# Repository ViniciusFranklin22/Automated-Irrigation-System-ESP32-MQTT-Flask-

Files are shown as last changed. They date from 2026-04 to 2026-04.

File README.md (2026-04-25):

# 🌿 Smart Irrigation System with ESP32 and IoT

This project was developed for real-time plant monitoring and automatic irrigation using ESP32, MQTT, and a web-based interface.

## 🚀 Features

- 📡 Real-time monitoring:
  - Soil moisture
  - Temperature
  - Air humidity
  - Light intensity

- 💧 Irrigation:
  - Manual (via web button)
  - Automatic (based on soil moisture threshold)

- ⚙️ Remote configuration:
  - Minimum soil moisture threshold
  - Minimum interval between irrigations
  - Pump activation time
  - Enable/disable automatic mode
  - Configuration is stored in ESP32 non-volatile memory, ensuring persistence after reboot

- 💡 System status indicators:
  - LED indicator for Wi-Fi connection status  
  - LED indicator for MQTT connection status  
  - Provides quick visual feedback for system debugging and reliability

- 📊 Web dashboard:
  - Historical graphs (24h, 48h, 1 week)
  - Device online/offline status
  - Last irrigation timestamp
  - Real data collected over several days
  - Clear visualization of sensor behavior, including soil moisture variation after irrigation events

## 🧠 Architecture

ESP32 → MQTT → Backend (Flask) → Web Dashboard  
ESP32 ← MQTT ← Backend (Flask) ← Web Dashboard  

- ESP32 publishes sensor data via MQTT  
- Backend stores data in CSV files using Pandas  
- Web interface consumes data through a Flask API  
- Commands are sent to the ESP32 via MQTT  

## 🛠️ Technologies Used

- Python (Flask, Pandas)  
- MQTT (paho-mqtt)  
- ESP32 (Arduino framework)  
- HTML + Bootstrap + Chart.js  
- KiCad  

## 🔌 Hardware Implementation

- Prototype built using a breadboard for data acquisition and testing  
- Sensors and ESP32 connected for real-world measurements  
- System validated with real environmental data over multiple days  

<p align="center">
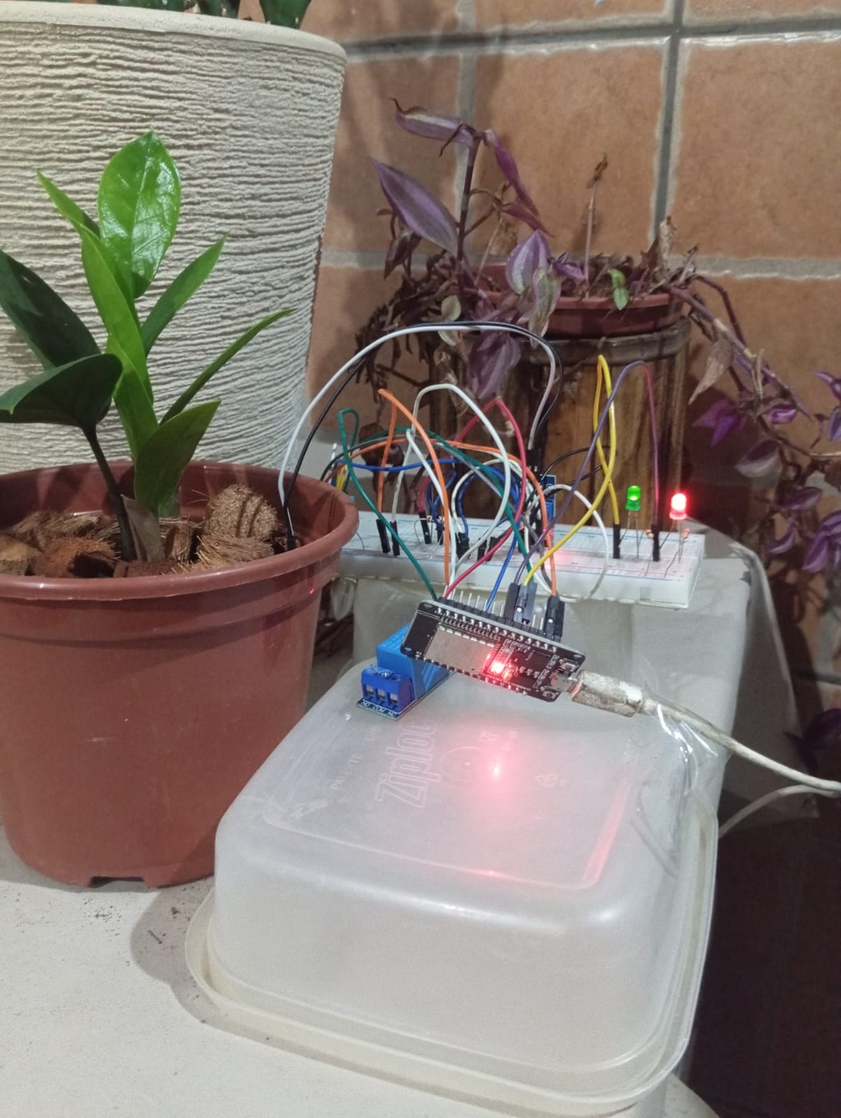
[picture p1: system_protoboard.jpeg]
  
</p>

## 🧩 PCB Design

- Custom PCB designed using KiCad  
- Developed aiming toward a future product-ready solution  

## 📷 Interface

<p align="center">
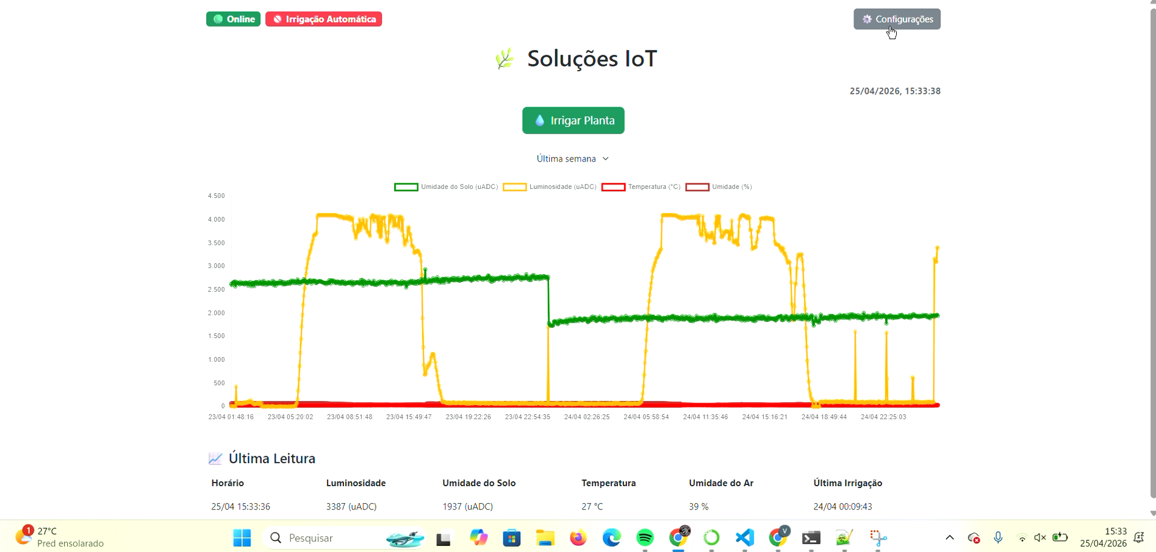
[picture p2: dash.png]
  
</p>

## ▶️ How to Run

1. Configure your MQTT broker  
2. Adjust file paths in the code  
3. Run the data collection scripts:
   - `server_get_msg.py`
   - `server_get_msg_irrig.py`
4. Start the Flask application:
   ```bash
   python main_flask.py

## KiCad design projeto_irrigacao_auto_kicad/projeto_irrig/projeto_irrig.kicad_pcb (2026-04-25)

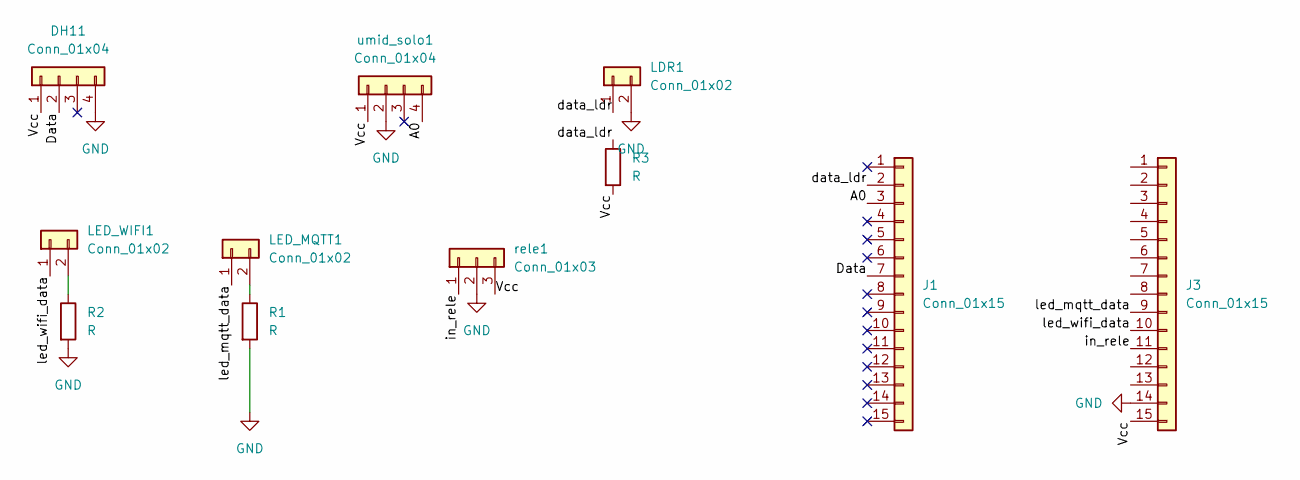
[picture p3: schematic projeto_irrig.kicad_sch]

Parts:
DH11: Conn_01x04; PinHeader_1x04_P2.54mm_Vertical
J1, J3: Conn_01x15; PinHeader_1x15_P2.54mm_Vertical
LDR1: Conn_01x02; PinHeader_1x02_P2.54mm_Vertical
LED_MQTT1: Conn_01x02; PinHeader_1x02_P2.54mm_Vertical
LED_WIFI1: Conn_01x02; PinHeader_1x02_P2.54mm_Vertical
R1, R2, R3: R; R_Axial_DIN0207_L6.3mm_D2.5mm_P7.62mm_Horizontal
rele1: Conn_01x03; PinHeader_1x03_P2.54mm_Vertical
umid_solo1: Conn_01x04; PinHeader_1x04_P2.54mm_Vertical

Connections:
/A0: J1.3, umid_solo1.4
/Data: DH11.2, J1.7
/Vcc: DH11.1, J3.15, R3.2, rele1.3, umid_solo1.1
/data_ldr: J1.2, LDR1.1, R3.1
/in_rele: J3.11, rele1.1
/led_mqtt_data: J3.9, LED_MQTT1.1
/led_wifi_data: J3.10, LED_WIFI1.1
GND: DH11.4, J3.14, LDR1.2, R1.2, R2.2, rele1.2, umid_solo1.2
unnamed: LED_MQTT1.2, R1.1
unnamed: LED_WIFI1.2, R2.1

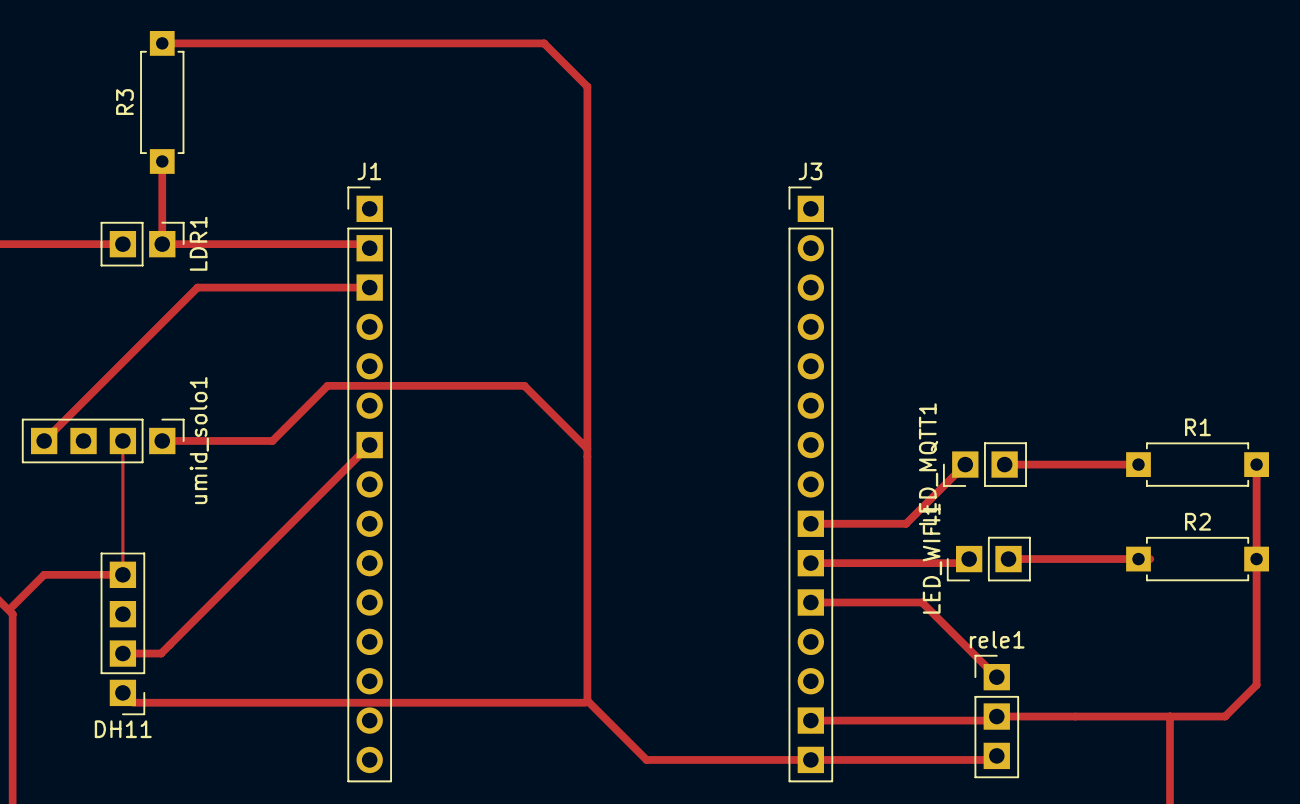
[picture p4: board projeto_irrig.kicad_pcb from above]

Board: 2 copper layers, 11 parts (0 on the bottom side), 10 nets.

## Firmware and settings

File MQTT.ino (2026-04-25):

/*
 * This ESP32 code is created by esp32io.com
 *
 * This ESP32 code is released in the public domain
 *
 * For more detail (instruction and wiring diagram), visit https://esp32io.com/tutorials/esp32-mqtt
 */


/*
Smart Plant Monitoring System
ESP32 + MQTT + Sensors

Features:
- Soil humidity monitoring
- Automatic irrigation
- Remote irrigation via MQTT
- Configurable thresholds
- Real time telemetry
- NTP timestamp
- WiFi + MQTT auto reconnection
*/

#include <WiFi.h>
#include <MQTTClient.h>
#include <ArduinoJson.h>
#include <time.h>
//#include <bits/stdc++.h>
#include <DHT11.h>
#include <Preferences.h>
Preferences prefs;


struct DHTData {
  int temperatura;
  int umidade;
};

// ===== PROTOTIPOS DAS FUNCOES =====

void connectToMQTT();
float get_ldr_value();
DHTData get_dht11_values();
float get_soil_humidity();
void regar_vaso_auto();
void check_threshold();
void sendToMQTT();
void messageHandler(String &topic, String &payload);
String get_real_time();
void regar_vaso_manual();
void reconnectToWiFi();
void ligar_bomba();
void create_var_flash();
void setUIntFromPayload(const char* key, String payload, uint &targetVar);

#define CLIENT_ID "ESP32-001"  // CHANGE IT AS YOU DESIRE

#define D_TEMP_PIN 33
#define DHT_READ_TIME 100000


DHT11 dht11(D_TEMP_PIN);
const char WIFI_SSID[] = "";              // CHANGE TO YOUR WIFI SSID
const char WIFI_PASSWORD[] = "";           // CHANGE TO YOUR WIFI PASSWORD
const char MQTT_BROKER_ADRRESS[] = "";  // CHANGE TO MQTT BROKER'S IP ADDRESS
const int MQTT_PORT = 1883;
const char MQTT_USERNAME[] = "";  // CHANGE IT IF REQUIRED
const char MQTT_PASSWORD[] = "";  // CHANGE IT IF REQUIRED
volatile bool flag = false;
String hora_ultima_irrigacao="0";
DHTData dht_cache;
unsigned long lastDHTRead = 0;
long timezone = -3;
byte daysavetime = 0;

// The MQTT topics that this device should publish/subscribe
unsigned long lastAutoCheck = 0;
int AUTO_CHECK_INTERVAL = 10000; // 10 segundos
bool irrigacao_em_curso = 0;

//#define LM75_ADDRESS 0x48  // Endereço padrão do LM75
//#define TEMP_REGISTER 0x00 // Registro de leitura de temperatura
#define PUBLISH_TOPIC "esp32-001/send"
#define INICIO_IRRIGACAO_PUBLISH_TOPIC "esp32-001/inicio_irrigacao"
#define SUBSCRIBE_TOPIC "esp32-001/receive"
#define TOPIC_CONFIG_THSHOLD "esp32-001/thshold"
#define TOPIC_CONFIG_MIN_ENTRE_IRRIGACAO "esp32-001/min_entre_irrigacao"
#define TOPIC_CONFIG_TEMPO_IRRIGACAO "esp32-001/tempo_irrigacao"
#define TOPIC_BOOL_IRRIGACAO_AUTO "esp32-001/auto_mode"
#define PINO_LED_WIFI 16 
#define PINO_LED_MQTT 17 
#define RW_MODE false
#define RO_MODE true
#define A0_LDR_PIN 36  
#define A1_HUM_PIN 39
//#define I2C_SDA 21  // SDA padrão no ESP32 DevKit v1
//#define I2C_SCL 22  // SCL padrão no ESP32 DevKit v1
#define PUBLISH_INTERVAL 1000  // 1 seconds
//#define TEMPO_RELE_ATIVO 5000 // tempo para irrigacao, era bom setar via MQTT, da liberdade ao user
#define RelePin  4 // pino ao qual o Módulo Relé está conectado
//#define tempo_min_entre_irrigacoes 1000 * 60 * 60 * 4 // era bom setar via MQTT, da liberdade ao user

WiFiClient network;
MQTTClient mqtt = MQTTClient(256);

// serao setadas a partir da memoria flash
bool irrig_auto; 
uint threshold_humidity; // so para testes como nao ta conectado a nada, era bom setar via MQTT, da liberdade ao user
uint TEMPO_RELE_ATIVO ;
uint tempo_min_entre_irrigacoes;

void create_var_flash(){


  prefs.begin("config", RO_MODE);           // Open our namespace (or create it if it doesn't exist) in RO mode.

  bool tpInit = prefs.isKey("nvsInit");       // Test for the existence of the "already initialized" key.
                                                
  if (tpInit == false) {
    
    prefs.end();
    prefs.begin("config", RW_MODE);
    // salvar valores de fabrica

    prefs.putBool("irrig_auto",0);
    prefs.putUInt("threshold_humidity",4000);
    prefs.putUInt("TEMPO_RELE_ATIVO",5000);
    prefs.putUInt("tempo_min_entre_irrigacoes",14400000); // 1000 * 60 * 60 * 4
    prefs.putBool("nvsInit", true); 
    prefs.end();
    prefs.begin("config", RO_MODE); 

  }

  irrig_auto = prefs.getBool("irrig_auto"); // flash
  threshold_humidity = prefs.getUInt("threshold_humidity"); // so para testes como nao ta conectado a nada, era bom setar via MQTT, da liberdade ao user
  TEMPO_RELE_ATIVO = prefs.getUInt("TEMPO_RELE_ATIVO");
  tempo_min_entre_irrigacoes = prefs.getUInt("tempo_min_entre_irrigacoes");
  // All done. Last run state (or the factory default) is now restored.
  prefs.end();

}

unsigned long ultima_irrigacao = 0;
unsigned long lastPublishTime = 0;

//float threshold_humidity = 2500;  // valor ADC para iniciar irrigação
int soil_cache;

void setup() {
  Serial.begin(115200);

  create_var_flash();

  //Wire.begin(I2C_SDA, I2C_SCL);  //  , SCL = GPIO 22 padrão no ESP32
  pinMode(RelePin, OUTPUT); // seta o pino como saída
  digitalWrite(RelePin, LOW); // seta o pino com nivel logico baixo

  pinMode(PINO_LED_WIFI,OUTPUT);
  pinMode(PINO_LED_MQTT,OUTPUT);
  digitalWrite(PINO_LED_WIFI,LOW);
  digitalWrite(PINO_LED_MQTT,LOW);

  // set the ADC attenuation to 11 dB (up to ~3.3V input)
  analogSetAttenuation(ADC_11db);
  WiFi.mode(WIFI_STA);
  WiFi.begin(WIFI_SSID, WIFI_PASSWORD);


  Serial.println("ESP32 - Connecting to Wi-Fi");

  while (WiFi.status() != WL_CONNECTED) {
    
    Serial.print(".A");
    digitalWrite(PINO_LED_WIFI,LOW);
    delay(500);
  }
  Serial.print("ESP32 IP Address: ");
  Serial.println(WiFi.localIP());
  digitalWrite(PINO_LED_WIFI,HIGH);
  //Serial.print("Ping broker: ");
  //Serial.println(WiFi.ping("192.168.0.174"));


  Serial.println();

  mqtt.begin(MQTT_BROKER_ADRRESS, MQTT_PORT, network);
  // Create a handler for incoming messages
  mqtt.onMessage(messageHandler);

  connectToMQTT();

  Serial.println("Contacting Time Server");
  configTime(3600 * timezone, daysavetime * 3600, "time.nist.gov", "0.pool.ntp.org", "1.pool.ntp.org");

}



void reconnectToWiFi() {

  if (WiFi.status() == WL_CONNECTED){
    digitalWrite(PINO_LED_WIFI,HIGH);
    return;
    }

  Serial.println("Reconectando ao WiFi...");

  WiFi.begin(WIFI_SSID, WIFI_PASSWORD);

  while (WiFi.status() != WL_CONNECTED) {
    Serial.print(".W");
    digitalWrite(PINO_LED_WIFI,LOW);
    delay(500);
  }
  digitalWrite(PINO_LED_WIFI,HIGH);
  Serial.println("\nWiFi reconectado!");
}

void connectToMQTT() {
  // Connect to the MQTT broker
  if (mqtt.connected()) {
    digitalWrite(PINO_LED_MQTT,HIGH);
    return;
    }
  

  Serial.print("ESP32 - Connecting to MQTT broker");

  while (!mqtt.connect(CLIENT_ID, MQTT_USERNAME, MQTT_PASSWORD) && WiFi.status() == WL_CONNECTED) {
    Serial.print(".B");
    digitalWrite(PINO_LED_MQTT,LOW);
    delay(100);
    }

  Serial.println();

  if (!mqtt.connected()) {
    Serial.println("ESP32 - MQTT broker Timeout!");
    return;
  }

  // Subscribe to a topic, the incoming messages are processed by messageHandler() function
  if (mqtt.subscribe(SUBSCRIBE_TOPIC)) {
      Serial.print("ESP32 - Subscribed to the topic: ");
      Serial.println(SUBSCRIBE_TOPIC);
  } else {
      Serial.print("ESP32 - Failed to subscribe to the topic: ");
}
    // Subscribe to a topic, the incoming messages are processed by messageHandler() function
  if (mqtt.subscribe(TOPIC_CONFIG_THSHOLD  )){
    Serial.print("ESP32 - Subscribed to the topic: ");
    Serial.println(TOPIC_CONFIG_THSHOLD);
    }
  else
    Serial.print("ESP32 - Failed to subscribe to the topic: ");

  

    // Subscribe to a topic, the incoming messages are processed by messageHandler() function
  if (mqtt.subscribe(TOPIC_CONFIG_MIN_ENTRE_IRRIGACAO )){
    Serial.print("ESP32 - Subscribed to the topic: ");
    Serial.println(TOPIC_CONFIG_MIN_ENTRE_IRRIGACAO);
  }
  else
    Serial.print("ESP32 - Failed to subscribe to the topic: ");


    // Subscribe to a topic, the incoming messages are processed by messageHandler() function
  if (mqtt.subscribe(TOPIC_CONFIG_TEMPO_IRRIGACAO)){
    Serial.print("ESP32 - Subscribed to the topic: ");
    Serial.println(TOPIC_CONFIG_TEMPO_IRRIGACAO);
  }
  else
    Serial.print("ESP32 - Failed to subscribe to the topic: ");

    // Subscribe to a topic, the incoming messages are processed by messageHandler() function
  if (mqtt.subscribe(TOPIC_BOOL_IRRIGACAO_AUTO)){
    Serial.print("ESP32 - Subscribed to the topic: ");
    Serial.println(TOPIC_BOOL_IRRIGACAO_AUTO);
  }
  else
    Serial.print("ESP32 - Failed to subscribe to the topic: ");

  
  Serial.println("ESP32  - MQTT broker Connected!");
  digitalWrite(PINO_LED_MQTT,HIGH);
}

float get_ldr_value() {
  int samples = 5;
  long sum = 0;

  for (int i = 0; i < samples; i++) {
    sum += analogRead(A0_LDR_PIN);
    //delay(5);  // opcional, para dar tempo entre leituras
  }

  float media = sum / (float)samples;
  return media;
}



void update_dht() {

  if (millis() - lastDHTRead < 2000) return;

  int temperature = 0;
  int humidity = 0;

  if (dht11.readTemperatureHumidity(temperature, humidity) == 0) {
      dht_cache.temperatura = temperature;
      dht_cache.umidade = humidity;
  }

  lastDHTRead = millis();
}

float get_soil_humidity(){
  int samples = 5;
  long sum = 0;

  for (int i = 0; i < samples; i++) {
    sum += analogRead(A1_HUM_PIN);
    //delay(5);  // opcional, para dar tempo entre leituras
  }

  float media = sum / (float)samples;
  return media;
}




void sendToMQTT() {
  StaticJsonDocument<300> message;
  String timestamp = get_real_time(); 
  soil_cache = get_soil_humidity();
  int ldr_value = get_ldr_value();
  int temp_value = dht_cache.temperatura;
  int umid_value = dht_cache.umidade;

  message["timestamp"] = timestamp;
  message["soil_humidity"] = soil_cache;
  message["ldr_value"] = ldr_value;
  message["temp_value"] = temp_value;
  message["umid_value"] = umid_value;
  message["ultima_irrigacao"] = hora_ultima_irrigacao;
  message["threshold_humidity"] = threshold_humidity;
  message["TEMPO_RELE_ATIVO"] = TEMPO_RELE_ATIVO;
  message["tempo_min_entre_irrigacoes"] = tempo_min_entre_irrigacoes;
  message["bool_irrigacao_auto"] = irrig_auto;
  //message["irrigacao_em_curso"] = irrigacao_em_curso;

  char messageBuffer[384];
  serializeJson(message, messageBuffer);

  mqtt.publish(PUBLISH_TOPIC, messageBuffer);  // terceiro parâmetro = retain


  Serial.println("ESP32 - sent to MQTT:");
  Serial.print("- topic: ");
  Serial.println(PUBLISH_TOPIC);
  Serial.print("- payload:");
  Serial.println(messageBuffer);
  

}


void messageHandler(String &topic, String &payload) {
  Serial.println("ESP32 - received from MQTT:");
  Serial.println("- topic: " + topic);
  Serial.println("- payload:");
  Serial.println(payload);

  
  if (topic == TOPIC_CONFIG_THSHOLD) {
      setUIntFromPayload("threshold_humidity", payload, threshold_humidity);
  }
  else if (topic == TOPIC_CONFIG_MIN_ENTRE_IRRIGACAO) {
      setUIntFromPayload("tempo_min_entre_irrigacoes", payload, tempo_min_entre_irrigacoes);
  }
  else if (topic == TOPIC_CONFIG_TEMPO_IRRIGACAO) {
      setUIntFromPayload("TEMPO_RELE_ATIVO", payload, TEMPO_RELE_ATIVO);
  }
  else if (topic == SUBSCRIBE_TOPIC) {
    if (payload == "Regar Vaso Agora") {
      regar_vaso_manual();

    }
  }
  else if (topic == TOPIC_BOOL_IRRIGACAO_AUTO) {
    irrig_auto = (payload == "1");
    prefs.begin("config", RW_MODE);
    prefs.putBool("irrig_auto",irrig_auto);
    prefs.end();
  }


}





String get_real_time(){
  char dateBuffer[20];
  char timeBuffer[20];
  char timestamp[40];

  struct tm timeinfo;
  if (getLocalTime(&timeinfo)) {
    
    strftime(dateBuffer, sizeof(dateBuffer), "%d/%m/%Y", &timeinfo);
    
    strftime(timeBuffer, sizeof(timeBuffer), "%H:%M:%S", &timeinfo);
  /*
    Serial.print("Date: ");
    Serial.print(dateBuffer);
    Serial.print(" - Time: ");
    Serial.println(timeBuffer);
    */
  } else {
    Serial.println("Failed to get time");
  }
  sprintf(timestamp, "%s %s", dateBuffer, timeBuffer);

  return timestamp;


}


void regar_vaso_auto() {
  if (millis() - ultima_irrigacao >= tempo_min_entre_irrigacoes) {  // Corrigido: >= e não <=
    ligar_bomba();
  } else {
    Serial.println("Irrigação ignorada: tempo mínimo ainda não passou.");
  }
  
}

void check_threshold(){
  if(soil_cache >= threshold_humidity){
    regar_vaso_auto();
  }

}
void regar_vaso_manual() {
  ligar_bomba();
  
}

void ligar_bomba(){
    Serial.println("Iniciando irrigação...");
    irrigacao_em_curso = 1;
    String timestamp_inicio = get_real_time(); 
    sendToMQTT_Irrigacao(timestamp_inicio,"",0);
		digitalWrite(RelePin, HIGH); // Liga relé (pode ser LOW dependendo do módulo!)
		delay(TEMPO_RELE_ATIVO);    // Espera o tempo de irrigação
		digitalWrite(RelePin, LOW); // Desliga relé
    irrigacao_em_curso = 0;
    String timestamp_fim = get_real_time(); 
    sendToMQTT_Irrigacao(timestamp_inicio,timestamp_fim,1); 
		Serial.println("Irrigação finalizada.");
		hora_ultima_irrigacao = get_real_time(); 
		ultima_irrigacao = millis(); // Atualiza tempo da última irrigação
		mqtt.publish(SUBSCRIBE_TOPIC, "1");
}



void setUIntFromPayload(const char* key, String payload, uint &targetVar) {
    targetVar = strtoul(payload.c_str(), NULL, 10); // converte para uint
    prefs.begin("config", RW_MODE);
    prefs.putUInt(key, targetVar);
    prefs.end();
}

void sendToMQTT_Irrigacao(String timestamp_inicio, String timestamp_fim,bool finalizada) {
  StaticJsonDocument<200> message;
  

  message["timestamp_inicio"] = timestamp_inicio;
  message["irrigacao_em_curso"] = irrigacao_em_curso;
  message["timestamp_fim"] = timestamp_fim;
  message["irrigacao_finalizada"] = finalizada;

  char messageBuffer[256];
  serializeJson(message, messageBuffer);

  mqtt.publish(INICIO_IRRIGACAO_PUBLISH_TOPIC, messageBuffer);  // terceiro parâmetro = retain


  Serial.println("ESP32 - sent to MQTT:");
  Serial.print("- topic: ");
  Serial.println(PUBLISH_TOPIC);
  Serial.print("- payload:");
  Serial.println(INICIO_IRRIGACAO_PUBLISH_TOPIC);
  

}
void loop() {



  reconnectToWiFi();

  if (!mqtt.connected() && WiFi.status() == WL_CONNECTED ) {
    connectToMQTT();
  }


  mqtt.loop();


  update_dht();
  if (millis() - lastPublishTime >= PUBLISH_INTERVAL) {
      sendToMQTT();
      lastPublishTime = millis();
  }

if (irrig_auto && millis() - lastAutoCheck >= AUTO_CHECK_INTERVAL) {
    check_threshold();
    lastAutoCheck = millis();
}
  
}

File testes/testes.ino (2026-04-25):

/**
 * DHT11 Sensor Reader
 * This sketch reads temperature and humidity data from the DHT11 sensor and prints the values to the serial port.
 * It also handles potential error states that might occur during reading.
 *
 * Author: Dhruba Saha
 * Version: 2.1.0
 * License: MIT
 */

// Include the DHT11 library for interfacing with the sensor.
#include <DHT11.h>
#define LIGHT_SENSOR_PIN 36 // ESP32 pin GIOP36 (ADC0)
#define SOIL_SENSOR_PIN 39
#define RelePin  4 // pino ao qual o Módulo Relé está conectado


// Create an instance of the DHT11 class.
// - For Arduino: Connect the sensor to Digital I/O Pin 2.
// - For ESP32: Connect the sensor to pin GPIO2 or P2.
// - For ESP8266: Connect the sensor to GPIO2 or D4.
DHT11 dht11(2);

void setup() {
    // Initialize serial communication to allow debugging and data readout.
    // Using a baud rate of 9600 bps.
    Serial.begin(9600);
    pinMode(RelePin, OUTPUT); // seta o pino como saída
    digitalWrite(RelePin, LOW); // seta o pino com nivel logico baixo

    // Uncomment the line below to set a custom delay between sensor readings (in milliseconds).
    analogSetAttenuation(ADC_11db);

    dht11.setDelay(1000); // Set this to the desired delay. Default is 500ms.
}

void loop() {
    int temperature = 0;
    int humidity = 0;

    // Attempt to read the temperature and humidity values from the DHT11 sensor.
    int result = dht11.readTemperatureHumidity(temperature, humidity);

    // Check the results of the readings.
    // If the reading is successful, print the temperature and humidity values.
    // If there are errors, print the appropriate error messages.

    int analogValue = analogRead(LIGHT_SENSOR_PIN);
    Serial.print("Luminosidade: \t");
    Serial.print(analogValue);

    int analogValue_2 = analogRead(SOIL_SENSOR_PIN);
    Serial.print("| Solo Humidade: \t");
    Serial.print(analogValue_2);

    if (analogValue < 600){
      digitalWrite(RelePin, HIGH);
    }
    else{
      digitalWrite(RelePin, LOW);
    }
    if (result == 0) {
        Serial.print("| Temperature: ");
        Serial.print(temperature);
        Serial.print(" °C\t| Humidity: ");
        Serial.print(humidity);
        Serial.println(" %");
    } else {
        // Print error message based on the error code.
        Serial.println(DHT11::getErrorString(result));
    }
}
